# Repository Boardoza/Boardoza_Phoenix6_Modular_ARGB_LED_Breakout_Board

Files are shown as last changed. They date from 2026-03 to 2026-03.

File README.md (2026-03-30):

# Boardoza Phoenix6 Breakout Board

The **Boardoza Phoenix6** is a compact, circular **addressable RGB lighting breakout board** featuring **six RGB LEDs** arranged in a ring configuration. Each LED is individually addressable, allowing precise control over color and brightness for dynamic lighting effects.

With its modular and chainable design, multiple B-Phoenix6-BRK boards can be connected to create custom lighting patterns, symbols, or visual indicators. Supporting **both 3.3V and 5V logic levels,** the board is fully compatible with common microcontrollers and development platforms. This makes it a reliable choice for DIY electronics, decorative lighting, wearables, and interactive display applications, whether for prototyping or finished projects.

## [Click here to purchase!](https://www.ozdisan.com/ureticiler/boardoza)
| Front Side | Back Side |
|:---:|:---:|
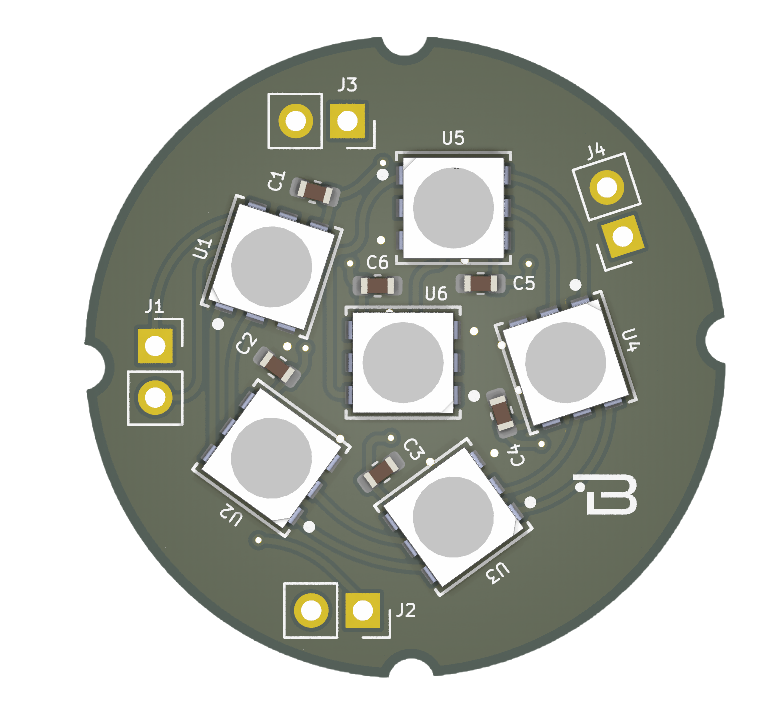
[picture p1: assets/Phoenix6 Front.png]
Phoenix6 Front
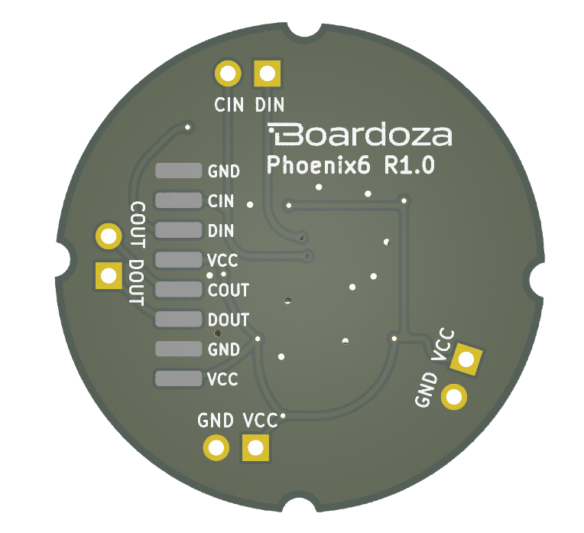
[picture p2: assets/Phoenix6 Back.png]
Phoenix6 Back
|  |  |

---

## Key Features

- **6x Addressable RGB LEDs:** Each LED can be individually controlled for color and brightness, enabling dynamic lighting effects and smooth animations.  
- **Modular Daisy-Chain Design:** Multiple boards can be connected to build custom lighting patterns and effects.
- **Dual Voltage Compatibility:** Operates with both 3.3 V and 5 V power supplies.
- **Logic Level Support:** Fully compatible with **TTL and CMOS** logic systems.
- **Flexible Connection Options:** Includes both **SMD and Through-Hole (THR) pads** for input and output connections.
- **Creative Application Ready:** Suitable for interactive lighting, wearables, decorative projects, and visual indicators.

---

## Technical Specifications

**Model:** Phoenix6  
**Manufacturer:** Boardoza  
**Function:** Individually Addressable RGB Lighting  
**Input Voltage:** 3.3 V / 5 V  
**LED Model:** T3A33BRG-H9C0002X1U1930   
**Number of LEDs:** 6  
**LED Type:** Individually addressable RGB LEDs  
**Logic Compatibility:** TTL / CMOS  
**Data Interface:** Serial Data & Clock (DIN / CIN / DOUT / COUT)  
**Daisy-Chain Support:** Yes  
**Operating Temperature:** -40 °C to +85 °C  
**Board Dimensions:** 31.79 mm × 31.71 mm  

---

## Board Pinout

### ( J1 ) Output Connector

| Pin Number | Pin Name | Description |
| :---: | :---: | --- |
| 1 | DOUT | Serial data output |
| 2 | COUT | Clock output |

### ( J2 ) Input Connector

| Pin Number | Pin Name | Description |
| :---: | :---: | --- |
| 1 | DIN | Serial data input |
| 2 | CIN | Clock input |

### ( J3 ) Power Connector

| Pin Number | Pin Name | Description |
| :---: | :---: | --- |
| 1 | VCC | Power supply (3.3V / 5V) |
| 2 | GND | Ground |

### ( J4 ) Power Connector

| Pin Number | Pin Name | Description |
| :---: | :---: | --- |
| 1 | VCC | Power supply (3.3V / 5V) |
| 2 | GND | Ground |

---

## Board Dimensions

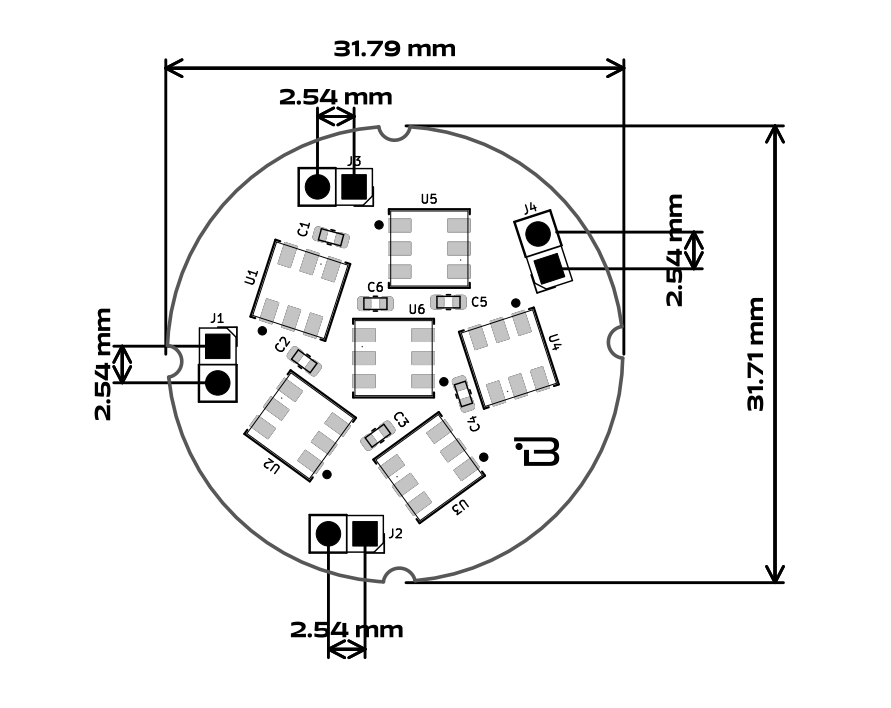
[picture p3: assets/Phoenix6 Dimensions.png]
Phoenix6 Dimensions


---

## Step Files

[Boardoza Phoenix6.step](./assets/Phoenix6%20Step.step)

---

## Datasheet

[T3A33BRG Datasheet](./assets/Phoenix6%20Datasheet.pdf)

---

## Version History

- **V1.0.0** – Initial Release

---

## Support

- For questions or technical support, please contact **support@boardoza.com**

---

## **License**

This repository contains both hardware and software components:

### **Hardware Design**

[][cc-by-sa]

All hardware design files are licensed under [Creative Commons Attribution-ShareAlike 4.0 International License][cc-by-sa].

[cc-by-sa]: http://creativecommons.org/licenses/by-sa/4.0/
[cc-by-sa-shield]: https://img.shields.io/badge/License-CC%20BY--SA%204.0-lightgrey.svg

### **Software/Firmware**

[][bsd]

All software and firmware are licensed under [BSD 3-Clause License][bsd].

[bsd]: https://opensource.org/licenses/BSD-3-Clause
[bsd-shield]: https://img.shields.io/badge/License-BSD%203--Clause-blue.svg

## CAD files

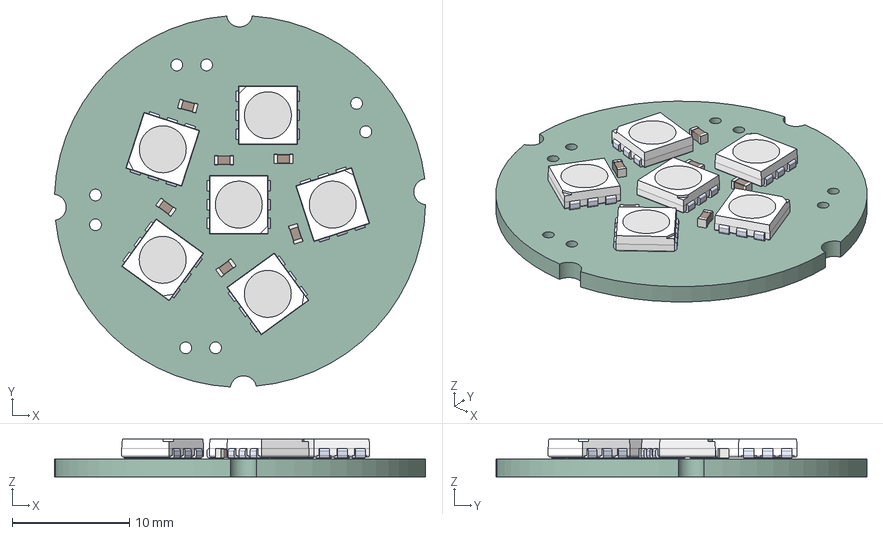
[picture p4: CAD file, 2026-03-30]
assets/Phoenix6 Step.step
31.6 x 31.6 x 3.20 mm
LTST-G563ZEGBW--3DModel-STEP-510211 x 6
C_0603_1608Metric x 6
B-Phoenix6-BRK_PCB

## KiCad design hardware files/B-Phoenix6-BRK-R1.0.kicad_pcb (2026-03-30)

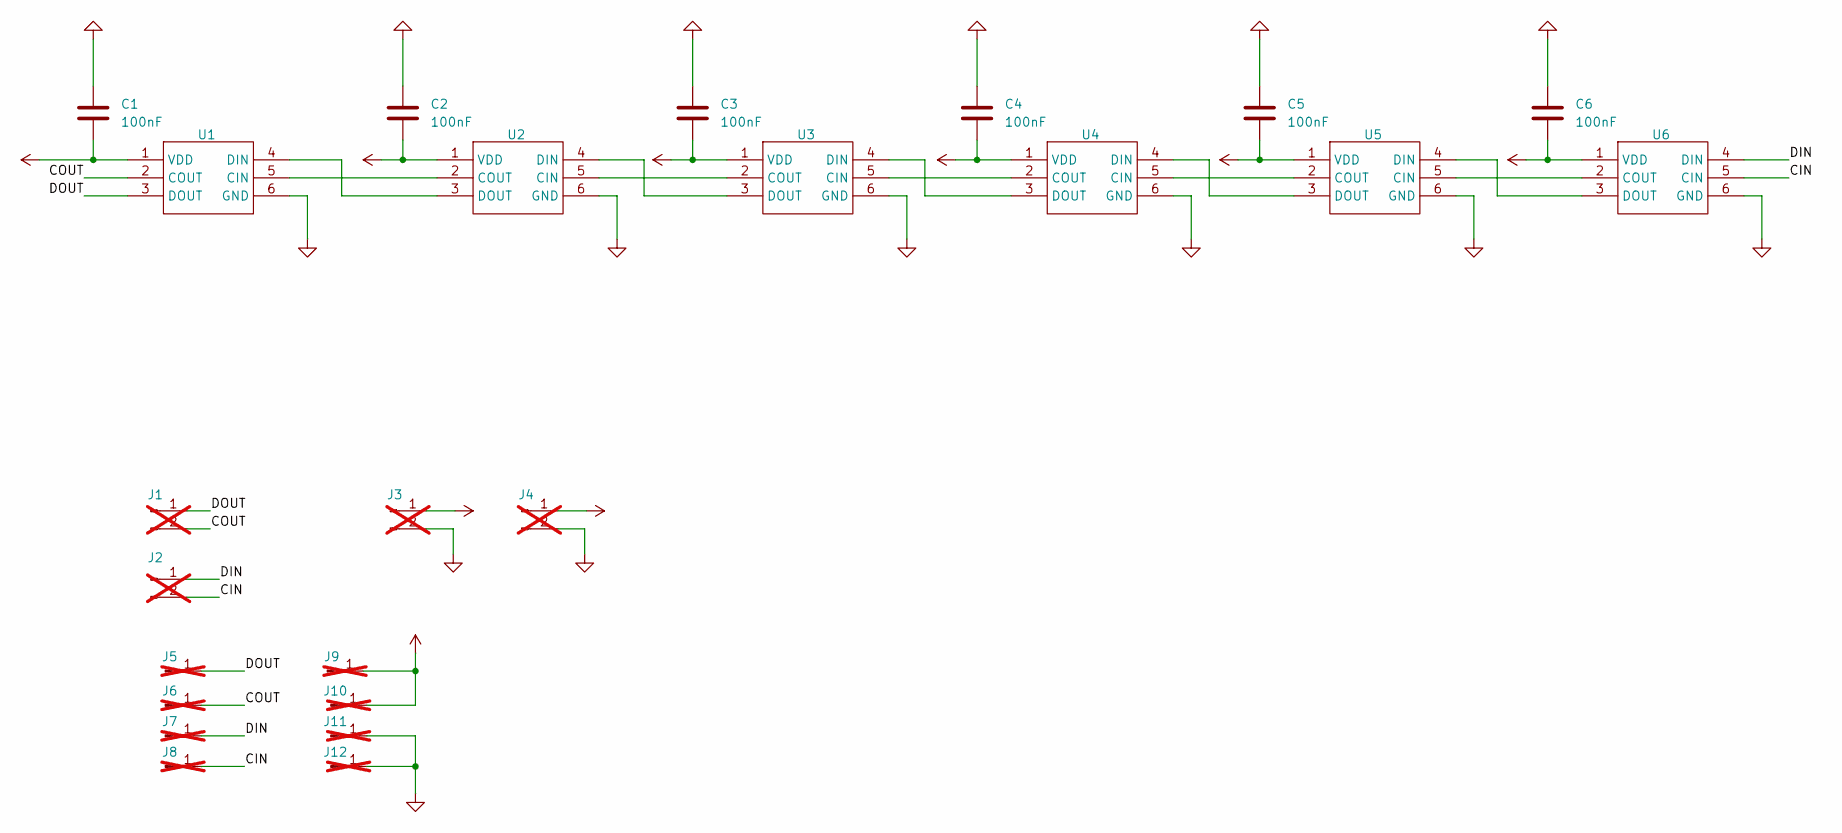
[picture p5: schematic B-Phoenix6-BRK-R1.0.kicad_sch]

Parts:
C1, C2, C3, C4, C5, C6: 100nF; C_0603_1608Metric; MPN MCF03KTB500104
J1, J2, J3, J4: Conn_01x02_Pin; PinSocket_1x02_P2.54mm_Vertical; not fitted
J5, J6, J7, J8, J9, J10, J11, J12: Conn_01x01_Pin; SolderWirePad_1x01_SMD_1x2mm; not fitted
U1, U2, U3, U4, U5, U6: T3A33BRG-H9C0002X1U1930_HVK; MPN T3A33BRG-H9C0002X1U1930

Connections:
/CIN: J2.2, J8.1, U6.5 (CIN)
/COUT: J1.2, J6.1, U1.2 (COUT)
/DIN: J2.1, J7.1, U6.4 (DIN)
/DOUT: J1.1, J5.1, U1.3 (DOUT)
GND: C1.1, C2.1, C3.1, C4.1, C5.1, C6.1, J3.2, J4.2, J11.1, J12.1, U1.6 (GND), U2.6 (GND), U3.6 (GND), U4.6 (GND), U5.6 (GND), U6.6 (GND)
unnamed: U1.5 (CIN), U2.2 (COUT)
unnamed: U1.4 (DIN), U2.3 (DOUT)
unnamed: U2.5 (CIN), U3.2 (COUT)
unnamed: U2.4 (DIN), U3.3 (DOUT)
unnamed: U3.5 (CIN), U4.2 (COUT)
unnamed: U3.4 (DIN), U4.3 (DOUT)
unnamed: U4.5 (CIN), U5.2 (COUT)
unnamed: U4.4 (DIN), U5.3 (DOUT)
unnamed: U5.5 (CIN), U6.2 (COUT)
unnamed: U5.4 (DIN), U6.3 (DOUT)
VCC: C1.2, C2.2, C3.2, C4.2, C5.2, C6.2, J3.1, J4.1, J9.1, J10.1, U1.1 (VDD), U2.1 (VDD), U3.1 (VDD), U4.1 (VDD), U5.1 (VDD), U6.1 (VDD)

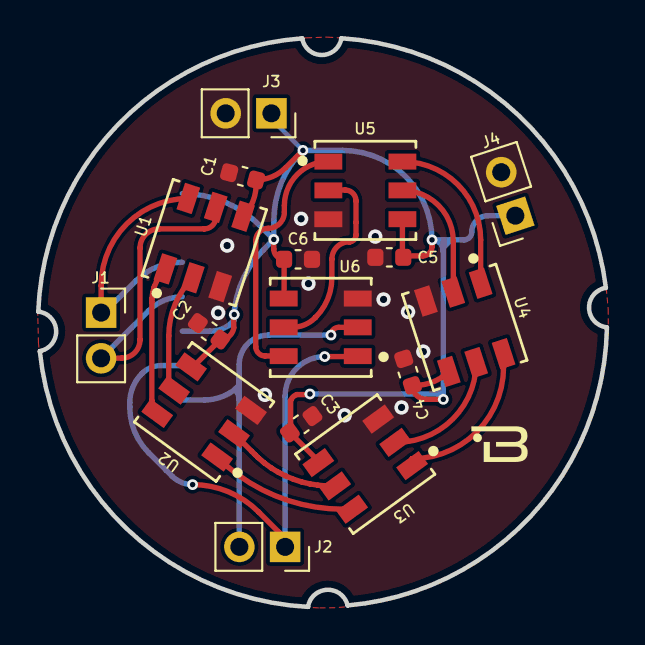
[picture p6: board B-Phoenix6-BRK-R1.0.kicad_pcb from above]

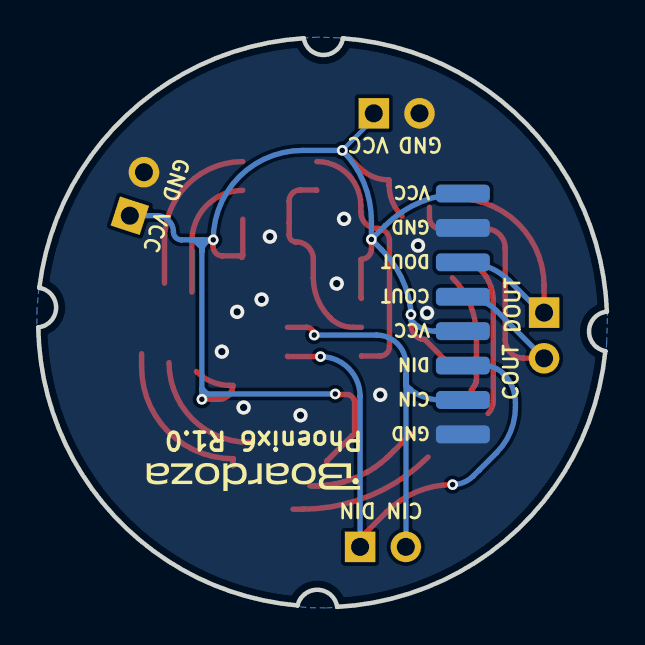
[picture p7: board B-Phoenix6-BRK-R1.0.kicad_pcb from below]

Board: 2 copper layers, 31.6 x 31.6 mm, 24 parts (8 on the bottom side), 16 nets.

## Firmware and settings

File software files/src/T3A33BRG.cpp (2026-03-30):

#include "T3A33BRG.h"

/**
 * @brief Constructor for the T3A33BRG class.
 *
 * Initializes the T3A33BRG object by assigning the provided data and clock pins
 * to the internal variables `_dataPin` and `_clockPin`. These pins are later used
 * for communication with the LED controller.
 *
 * @param dataPin The pin number used for data transmission to the LED controller.
 * @param clockPin The pin number used for clock signal transmission to the LED controller.
 *
 * Example usage:
 * @code
 * T3A33BRG ledController(25, 26);  // Create an instance with data pin 25 and clock pin 26
 * @endcode
 */
T3A33BRG::T3A33BRG(uint8_t dataPin, uint8_t clockPin) : _dataPin(dataPin), _clockPin(clockPin) {}

/**
 * @brief Initializes the T3A33BRG LED controller.
 *
 * This function sets up the data and clock pins as outputs and ensures
 * that their initial states are set to LOW. It should be called before
 * using any other functions of the T3A33BRG class.
 * 
 * Example usage:
 * @code
 * ledController.begin();  // Initialize the controller
 * @endcode
 */
void T3A33BRG::begin() {
    pinMode(_dataPin, OUTPUT);
    pinMode(_clockPin, OUTPUT);

    digitalWrite(_dataPin, LOW);
    digitalWrite(_clockPin, LOW);
}

/**
 * @brief Sends a 32-bit data frame to the LED controller.
 *
 * This function constructs a 32-bit data frame using the provided flag, dimming,
 * and RGB color values, then sends it bit by bit over the data and clock pins.
 * It is used to control the brightness and color of LEDs.
 *
 * @param flag    3-bit flag (bits 31 to 29) that defines specific settings for the LED.
 * @param dimming 5-bit dimming value (bits 28 to 24) that adjusts the brightness.
 * @param blue    8-bit blue color intensity (bits 23 to 16).
 * @param green   8-bit green color intensity (bits 15 to 8).
 * @param red     8-bit red color intensity (bits 7 to 0).
 *
 * Example usage:
 * @code
 * ledController.send32Bit(0x07, 0x1F, 255, 128, 64);  // Send a 32-bit frame
 * @endcode
 */
void T3A33BRG::send32Bit(uint32_t flag, uint32_t dimming, uint32_t blue, uint32_t green, uint32_t red) {
    uint32_t data = 0;

     // Flag (3 bit) [31:29]
    data |= ((uint32_t)(flag & 0x07)) << 29;

    // Dimming (5 bit) [28:24]
    data |= ((uint32_t)(dimming & 0x1F)) << 24;

    // Blue (8 bit) [23:16]
    data |= ((uint32_t)(blue & 0xFF)) << 16;

    // Green (8 bit) [15:8]
    data |= ((uint32_t)(green & 0xFF)) << 8;

    // Red (8 bit) [7:0]
    data |= ((uint32_t)(red & 0xFF));

    for(int i = 31; i >= 0; i--) {
        digitalWrite(_dataPin, (data & (1UL << i)) ? HIGH : LOW);
        clockPulse();
    }
    
}

/**
 * @brief Generates a clock pulse on the clock pin.
 *
 * This function sets the clock pin (`_clockPin`) HIGH for 1 microsecond,
 * then LOW for another 1 microsecond to create a single clock pulse. It is used
 * to synchronize data transmission with the LED controller.
 * 
 * Example usage:
 * @code
 * ledController.clockPulse();  // Generate a single clock pulse
 * @endcode
 */
void T3A33BRG::clockPulse() {
    digitalWrite(_clockPin, HIGH);
    delayMicroseconds(1);
    digitalWrite(_clockPin, LOW);
    delayMicroseconds(1);
}

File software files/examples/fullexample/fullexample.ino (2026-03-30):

#include "EC1101S.h"
#include "T3A33BRG.h"

// Rotary Encoder Pins
#define TERMINAL_A 33
#define TERMINAL_B 21
#define SW         22

// LED Control Pins
#define DATA_PIN   25  // Suitable output pin
#define CLOCK_PIN  26  // Suitable output pin

// Create objects
EC1101S encoder(TERMINAL_A, TERMINAL_B, SW);
T3A33BRG ledController(DATA_PIN, CLOCK_PIN);

// Maximum number of LEDs
const uint8_t LED_COUNT = 12; // Total number of LEDs
uint8_t currentLED = 0;      // Index of the LED that is lit
uint8_t turnCounter = 0;     // Counter for 5 rotations
int8_t lastCount=0;
int8_t currentCount=0; 

/**
 * @brief Lights up a specific LED and turns off the rest.
 *
 * This function lights up the LED at the specified index while turning off
 * all the other LEDs. The `ledIndex` is wrapped around the maximum LED count (12)
 * using the modulo operation. 
 *
 * @param ledIndex The index of the LED to light up (0-based).
 *
 * The function sends the following commands:
 * - A reset command to turn off all LEDs.
 * - Commands to light up the specific LED and turn off others.
 * - A final command to ensure all LEDs are turned off at the end of the operation.
 *
 * Example usage:
 * @code
 * lightUpLED(5);  // Lights up the 5th LED.
 * @endcode
 */
void lightUpLED(uint8_t ledIndex) {
    uint8_t mode = ledIndex % 12;
    ledController.send32Bit(0, 0, 0, 0, 0);
    for (uint8_t i = 0; i <= LED_COUNT; i++) {
        if (i == mode) {
                ledController.send32Bit(0x07, 1, 0, 0, 255); // Turn on the LED
        } 
        else {
            ledController.send32Bit(0x07, 0, 0, 0, 0); // Turn off
        }
    }
   ledController.send32Bit(0x07, 31, 255, 255, 255); // Turn off   
}

/**
 * @brief Turns on LEDs with random colors and optionally turns them off.
 *
 * This function lights up LEDs with random colors for a total of 12 iterations.
 * The `order` parameter determines the modulo value to calculate the mode.
 * The `on_off` parameter is used to control the state, but its functionality is not fully implemented in the current version.
 *
 * @param order Determines the mode based on modulo 12 operation.
 * @param on_off Not fully implemented, reserved for controlling on/off state.
 *
 * The function performs the following steps:
 * - Sends an initial reset command to turn off all LEDs.
 * - Iterates through 12 LEDs, turning each one on with a random RGB value.
 * - Sends a final command to turn off all LEDs.
 *
 * Example usage:
 * @code
 * randomLEDOn(5, 1);  // Lights up LEDs with random colors.
 * @endcode
 */                                                                                                                                                                                                                                                                                                                                                                          
void randomLEDOn(uint8_t order, uint8_t on_off)
{
uint8_t i=0; 
uint8_t mode=order%12;
ledController.send32Bit(0, 0, 0, 0, 0); 
while (i<=12)
    {
    i++; 
    ledController.send32Bit(0x07, 1, (rand()%255), (rand()%255), (rand()%255));          
    }
ledController.send32Bit(0x07, 31, 255, 255, 255); // Turn off
}

void setup() {
    Serial.begin(115200);

    // Initialize the encoder and LED controller
    encoder.begin();
    ledController.begin();

    // Reset all LEDs initially
    ledController.send32Bit(0, 0, 0, 0, 0);
}

void loop() {

    encoder.update();

    currentCount = encoder.getCount();

    if (currentCount != lastCount) {
        //randomLEDOn(currentCount, 1);     // Uncomment this line if you want to use the randomLEDOn function
        // Determine direction
        if (currentCount > lastCount) {
            turnCounter++; // Clockwise -> Forward
            //if (turnCounter >= 1 && currentLED < LED_COUNT) { // use this block if you want to light all leds at the same time
            if (turnCounter >= 1 ) {                            // use this block if you want to light leds one by one
                currentLED++; // Light up the next LED
                turnCounter = 0; // Reset the counter
            }
        } else {
            turnCounter++; // Counter-clockwise -> Backward
            if (turnCounter >= 1 && currentLED > 0) {
                currentLED--; // Turn off the previous LED
                turnCounter = 0; // Reset the counter
            }
        }
    Serial.println(currentCount);

    // Change the LED
    lightUpLED(currentLED);     // Comment this line if you want to use the randomLEDOn function
    lastCount = currentCount;
    }
}

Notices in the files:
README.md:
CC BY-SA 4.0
